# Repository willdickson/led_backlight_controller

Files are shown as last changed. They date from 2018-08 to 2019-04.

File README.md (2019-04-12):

# led_backlight_controller 
Simple 4A LED backlight controller based on the LTC6992 voltage controlled PWM modulator. 

* [Schematic (PDF)](controller.pdf)
* [Bill-of-materials](bom.txt)

# PCB layout 
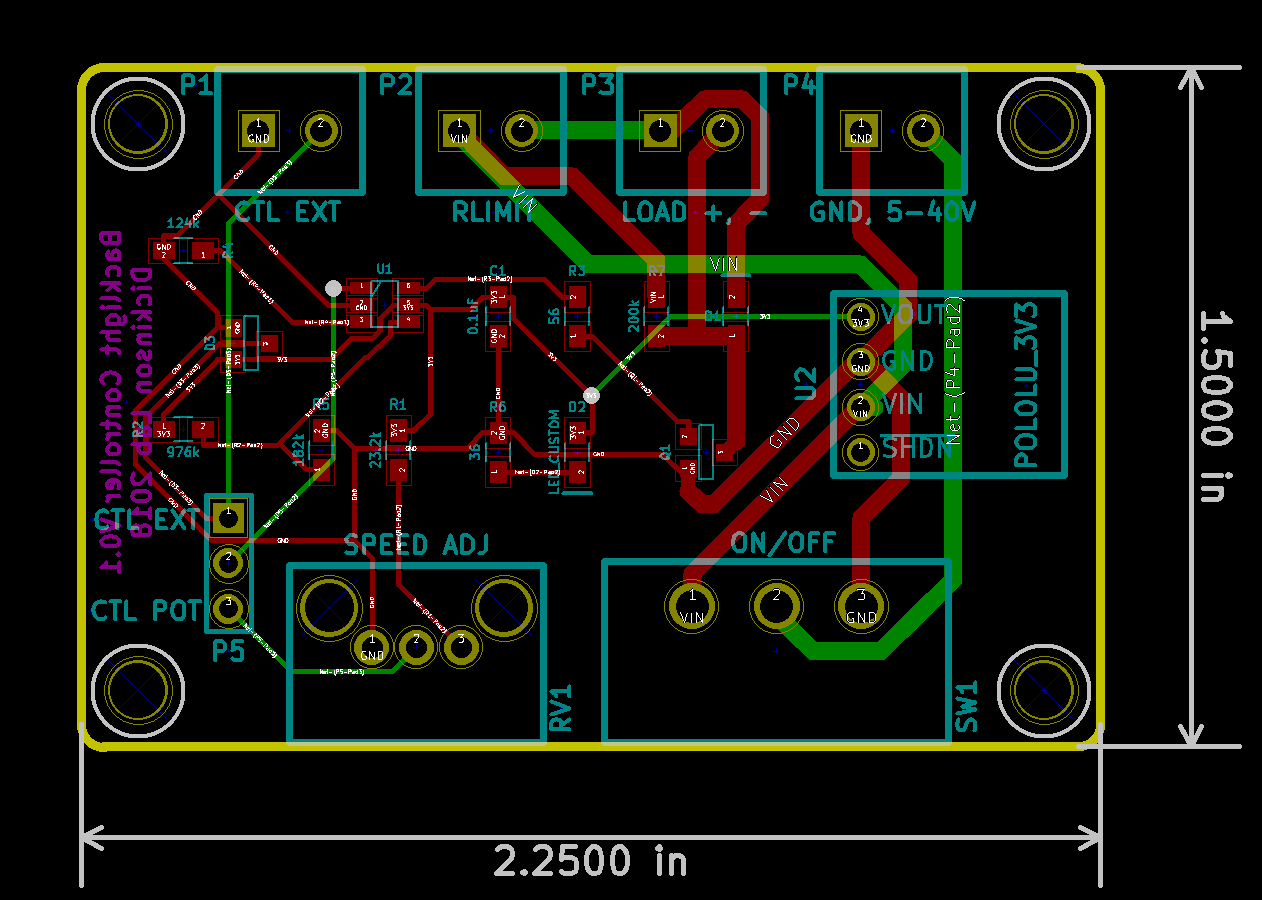
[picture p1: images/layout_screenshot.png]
layout


# License: 
Creative Commons Attribution 4.0 International CC BY 4.0

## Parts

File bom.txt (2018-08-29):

Part     Description                  Package     Vendor    Part Number                    Qty
----     -----------                  -------     ------    -----------                    ---
C1       capacitor   0.1uF            SM0603      Digikey   1276-1258-1-ND                  1
D1       diode, schottky (fast resp)  SM0603      Digikey   SDM2U40CSP-7BDICT-ND            1
D2       led blue (2.8Vf)             SM0603      Digikey   160-1827-1-ND                   1
D3       diode pair Schottky          SOT-23-3    Digikey   BAS70-04-E3-08                  1
P1-P4    terminal block, 3.5mm vert   custom      Digikey   ED2635-ND                       3
P5       break away header 0.1"       NA          Digikey   S1011EC-40-ND                   1
R1       resistor    23.2k            SM0603      Digikey   P23.2KHCT-ND                    1
R2       resistor    976k             SM0603      Digikey   RMCF0603FT976KCT-ND             1
R3       resistor    56               SM0603      Digikey   RHM56DCT-ND                     1
R4       resistor    124k             SM0603      Digikey   311-124KDCT-ND                  1
R5       resistor    182k             SMO603      Digikey   541-182KHCT-ND                  1
R6       resistor    36               SM0603      Digikey   311-36GRCT-ND                   1
R7       resistor    200k             SM0603      Digikey   RR08P200KDCT-ND                 1
RV1      potentiometer 10k            custom      Digikey   P3T9103-ND                      1
SW1      switch, slide, spdt          custom      Digikey   CKC5102-ND                      1
U1       Voltage controlled PWM       TSOT-23-6   Digikey   LTC6992CS6-1#TRMPBFCT-ND        1   
U2       3.3V Voltage Regulator       custom      Pololu    D24V3F3                         1
Q1       npn transistor 2A            SOT-23-3    Digikey   FMMT619CT-ND                    1
Q1       npm transistor 3A            SOT-23-3    Digikey   ZXTN25100BFHCT-ND               1
Q1       npm transistor 4A            SOT-23-3    Digikey   ZXTN25040DFHDKR-ND              1

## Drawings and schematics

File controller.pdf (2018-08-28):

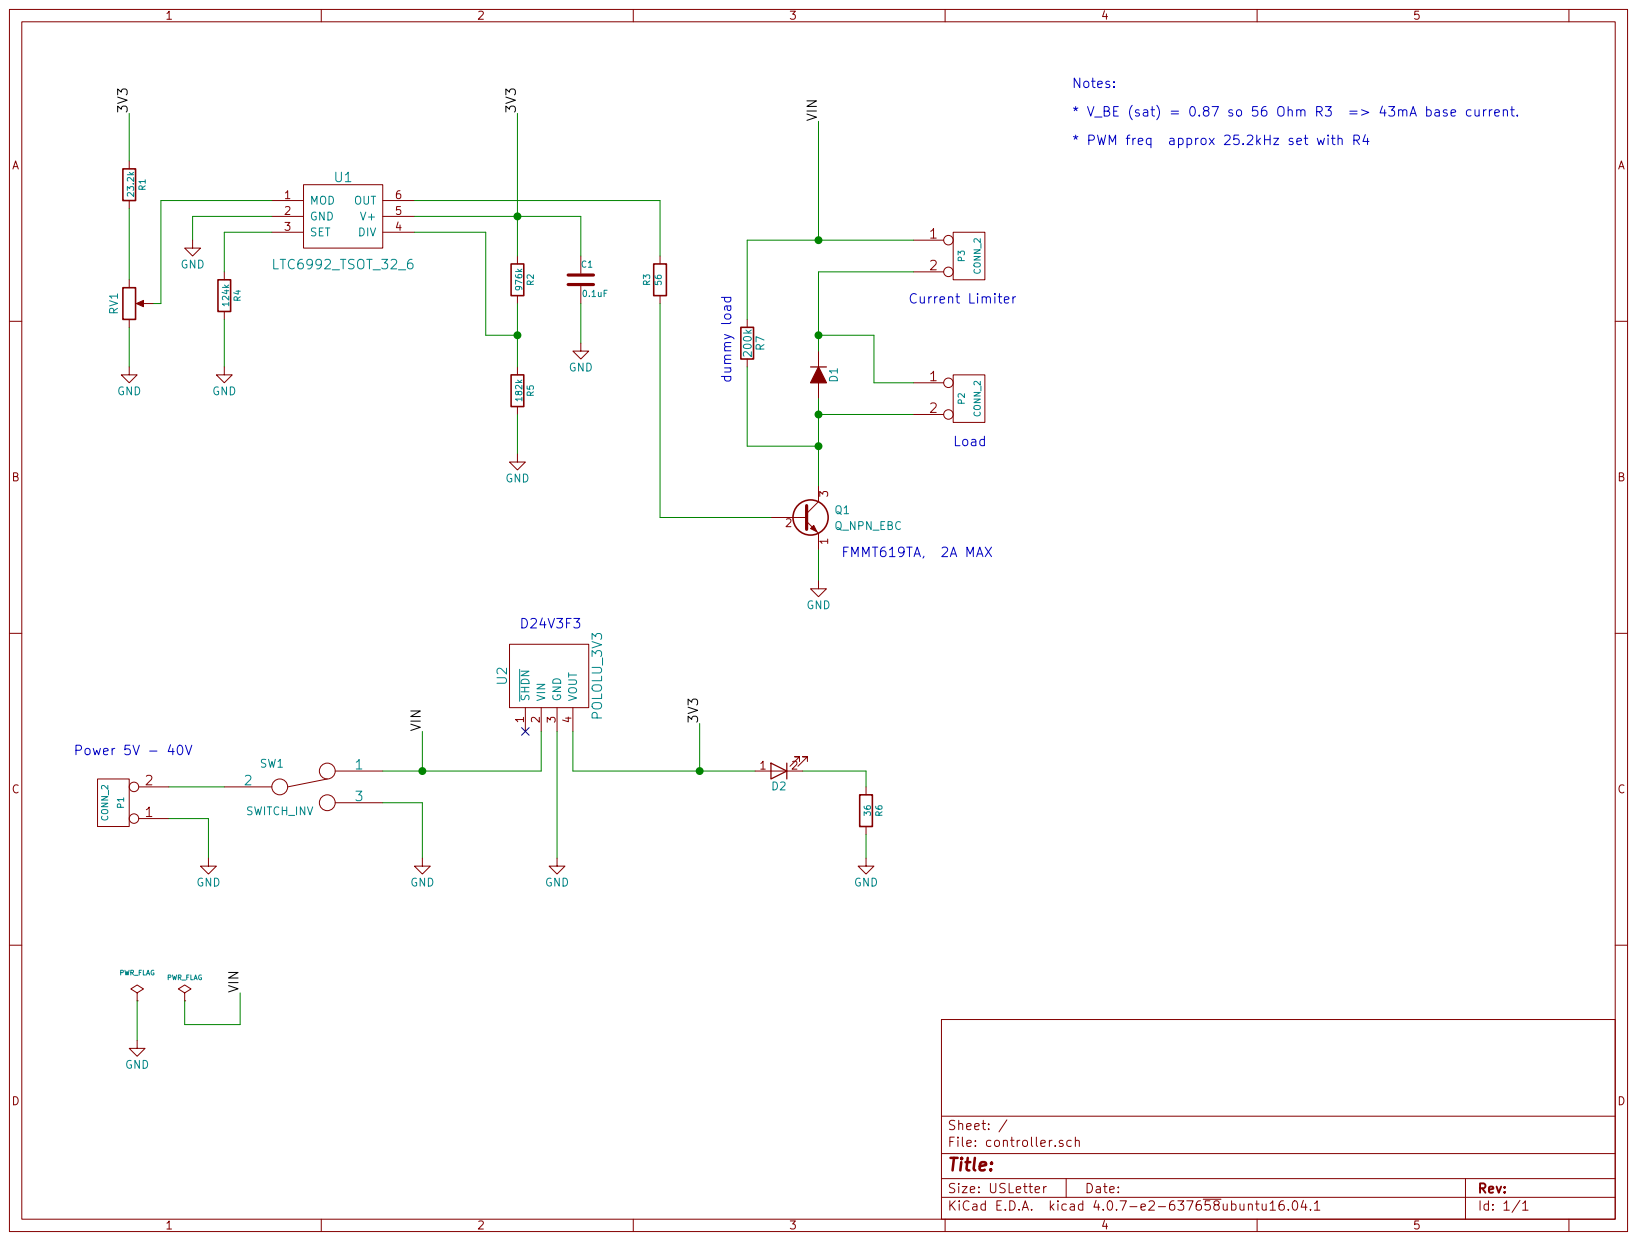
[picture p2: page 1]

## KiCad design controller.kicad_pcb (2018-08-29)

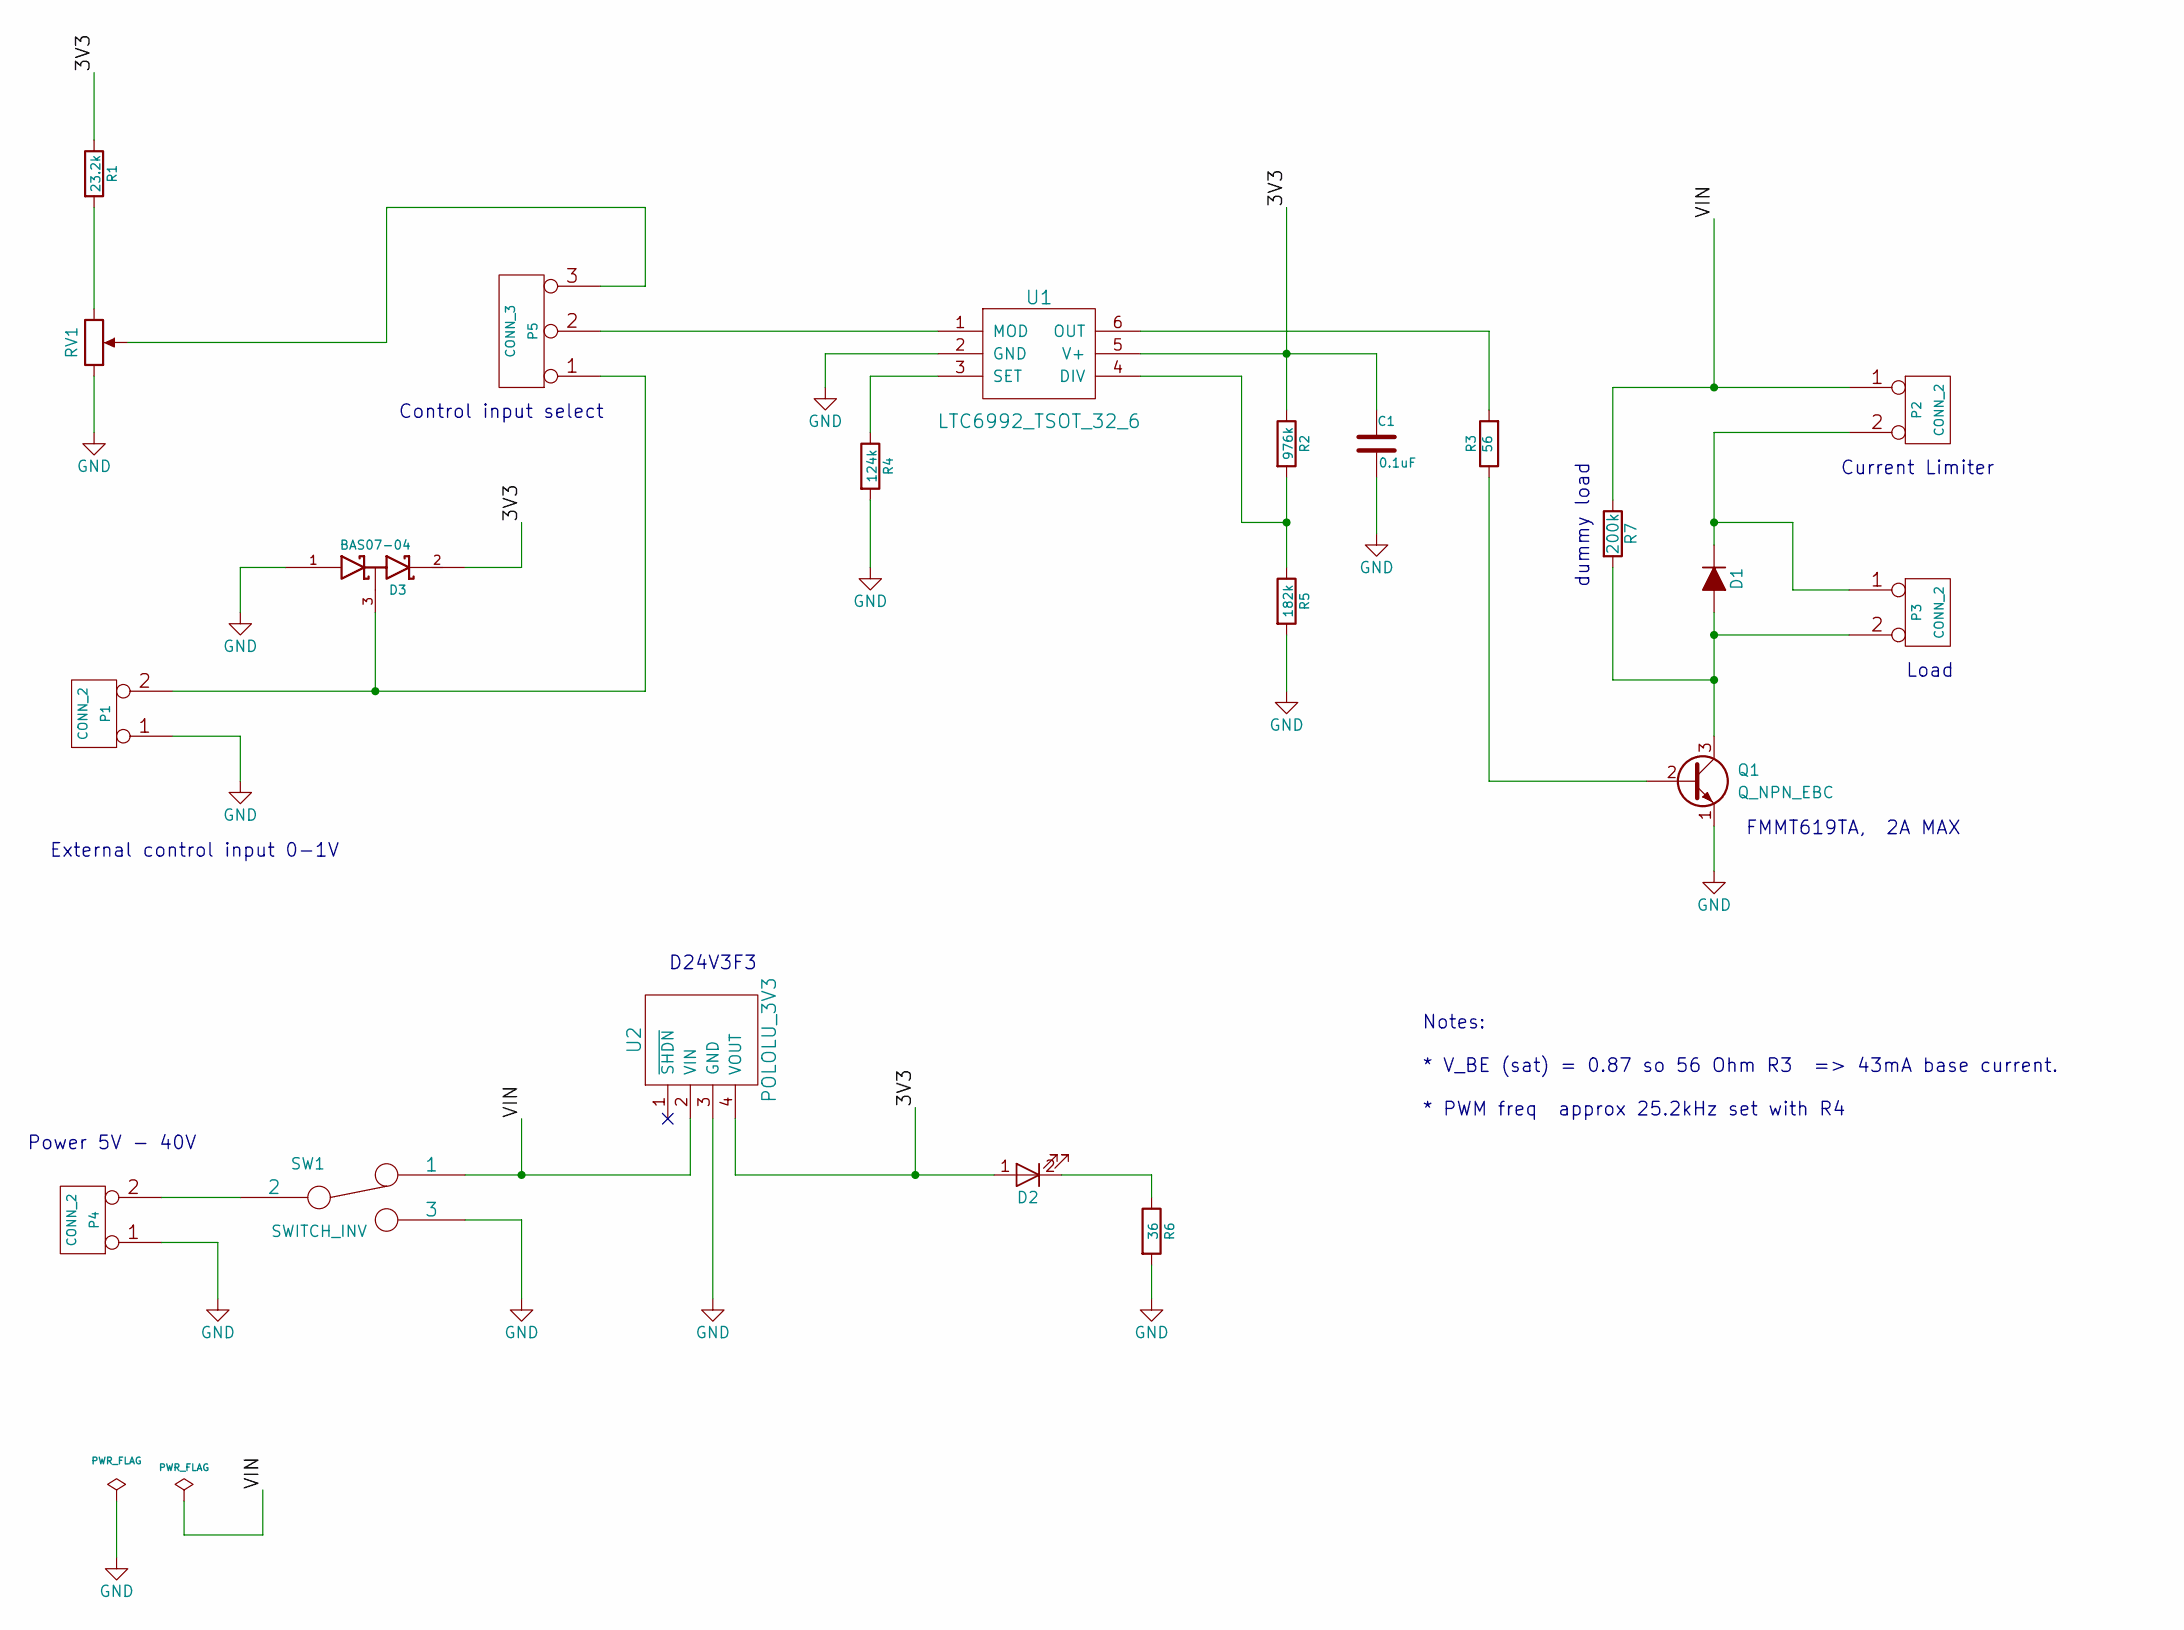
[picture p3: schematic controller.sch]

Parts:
C1: 0.1uF; R_0603_HandSoldering
D1: DIODE_CUSTOM; R_0603_HandSoldering
D2: LED_CUSTOM; R_0603_HandSoldering
D3: BAS07-04; SOT23EBC
P1, P2, P3, P4: CONN_2; BLOCK_CONN_2X1
P5: CONN_3; PIN_ARRAY_1X3
Q1: Q_NPN_EBC; SOT23EBC
R1: 23.2k; R_0603_HandSoldering
R2: 976k; R_0603_HandSoldering
R3: 56; R_0603_HandSoldering
R4: 124k; R_0603_HandSoldering
R5: 182k; R_0603_HandSoldering
R6: 36; R_0603_HandSoldering
R7: 200k; R_0603_HandSoldering
RV1: POT; POT_EVUE2J
SW1: SWITCH_INV; SLIDE_SWITCH
U1: LTC6992_TSOT_32_6; SOT23_6_CUSTOM
U2: POLOLU_3V3

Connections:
/3V3: C1.1, D2.1 (A), D3.2 (cathode), R1.1, R2.1, U1.5 (V+), U2.4 (VOUT)
/VIN: P2.1, R7.1, SW1.1, U2.2 (VIN)
GND: C1.2, D3.1 (Anode), P1.1, P4.1, Q1.1 (E), R4.2, R5.2, R6.2, RV1.1, SW1.3, U1.2 (GND), U2.3 (GND)
unnamed: D1.1 (A), P3.2 (PM), Q1.3 (C), R7.2
unnamed: D1.2 (K), P2.2 (PM), P3.1
unnamed: D2.2 (K), R6.1
unnamed: D3.3 (AK), P1.2 (PM), P5.1
unnamed: P4.2 (PM), SW1.2
unnamed: P5.2 (PM), U1.1 (MOD)
unnamed: P5.3, RV1.2
unnamed: Q1.2 (B), R3.1
unnamed: R1.2, RV1.3
unnamed: R2.2, R5.1, U1.4 (DIV)
unnamed: R3.2, U1.6 (OUT)
unnamed: R4.1, U1.3 (SET)

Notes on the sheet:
Power 5V - 40V
Load
dummy load
Current Limiter
FMMT619TA, 2A MAX
D24V3F3
Notes: * V_BE (sat) = 0.87 so 56 Ohm R3 => 43mA base current. * PWM freq approx 25.2kHz set with R4
External control input 0-1V
Control input select

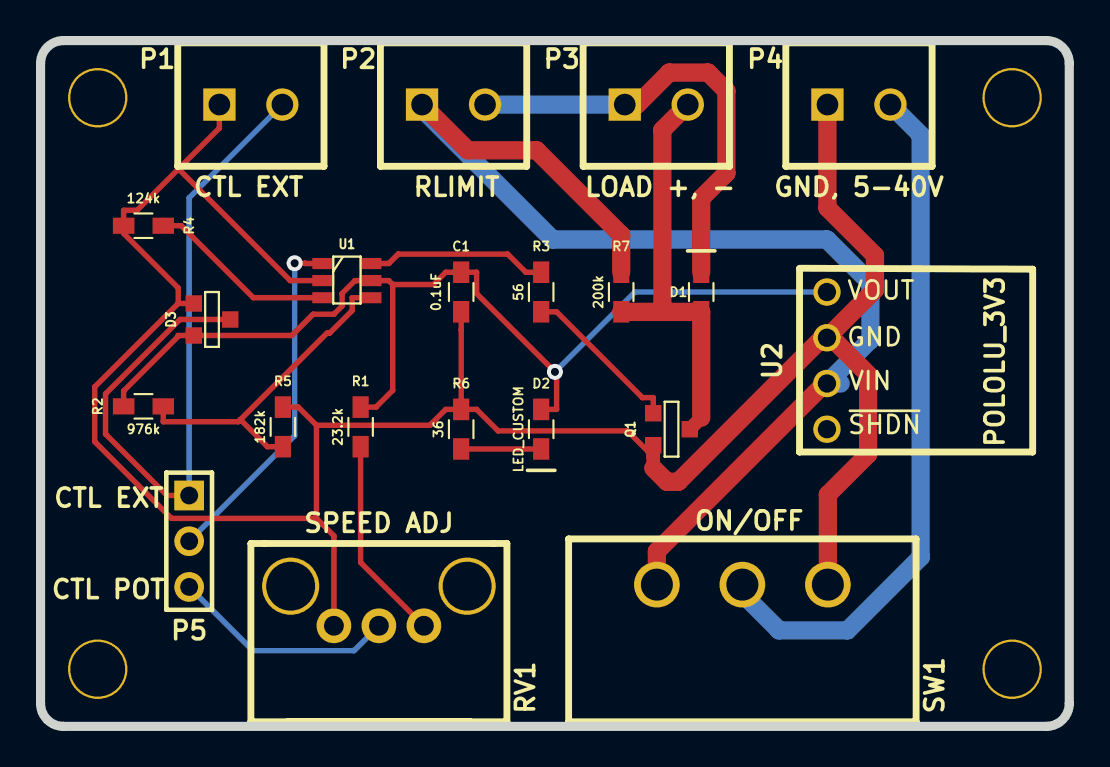
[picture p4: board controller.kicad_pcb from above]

Board: 2 copper layers, 57.2 x 38.1 mm, 24 parts (0 on the bottom side), 15 nets.

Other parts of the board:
M1, M2, M4: VAL**; MOUNT_HOLE_4_40

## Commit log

2018-08-28 Project creation.
    [controller-B.Cu.gbl, controller-B.Mask.gbs, controller-B.SilkS.gbo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]
2018-08-28 Added some higher current transistor options.
2018-08-29 Modified to add external 0-1V analog input control. Made .zip archive of gerber files.
    [controller-B.Cu.gbl, controller-B.Mask.gbs, controller-B.SilkS.gbo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]
2018-08-29 Added new components to bom.txt.
2018-08-31 Remade gerber and drill files.
    [controller-B.Cu.gbl, controller-B.Mask.gbs, controller-B.SilkS.gbo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]
2018-09-05 Updated gerber files.
    [controller-B.Cu.gbl, controller-B.Mask.gbs, controller-B.SilkS.gbo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]
